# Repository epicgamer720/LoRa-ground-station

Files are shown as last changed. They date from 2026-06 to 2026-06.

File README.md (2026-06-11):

# LoRa Ground Station

A compact, USB-connected LoRa receiver for pulling live telemetry off my rockets in flight. Built around an RP2040 + Semtech SX1262 on the 902–928 MHz ISM band, designed from scratch in KiCad. Pairs with my [rocket flight controller](https://github.com/epicgamer720/Flight-Controller-for-rockets).






## Why I built it

The flight controller sends telemetry down over LoRa, but that's only half the link — you need something on the ground to actually receive it. Rather than buy an off the shelf LoRa dev board, I wanted to try my hand at RF design. It plugs into a laptop over USB-C and streams the rocket's altitude and position to a terminal or display in real time. It was also my way into RF design getting the 50 Ω antenna trace, the impedance matching, the RF switch, and the SX1262's TCXO reference right is a different challenge from a normal digital board, and I wanted to learn it on real hardware.

## Use cases

- **Live flight telemetry** — receive altitude, velocity, and GPS position from the rocket during flight, in real time.
- **Recovery tracking** — read out the last known GPS coordinates to find the rocket after landing.
- **Range testing** — bench-test link distance and signal quality before committing to a flight.
- **General LoRa receiver / dev tool** — works as a USB LoRa node for any other long-range telemetry or sensor project, not just rockets.

## Specifications

| Subsystem | Part / detail |
|---|---|
| MCU | RP2040 — dual-core Cortex-M0+ |
| Radio | SX1262 — sub-GHz LoRa transceiver |
| Band | 902–928 MHz ISM (915 MHz, US) |
| RF switch | PE4259 — TX/RX antenna switching |
| Reference | 32 MHz TCXO (ECS-TXO) for the radio |
| Antenna | SMA connector |
| Flash | W25Q128 — 16 MB QSPI for firmware |
| Clock | 12 MHz crystal for the RP2040 |
| Power | AP2112K-3.3 LDO, USB-C |
| Controls | 2× tactile buttons (BOOT / RESET) |

## 
## Built with

[KiCad](https://www.kicad.org/) · [Macondo](https://macondo.hackclub.com/)

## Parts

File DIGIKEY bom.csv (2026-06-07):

Index | Quantity | Part Number | Manufacturer Part Number | Description | Customer Reference | Available | Backorder | Unit Price | Extended Price USD
1 | 2 | 2073-RFPC-SMA28-F-ND | RFPC-SMA28-F | SMA VERTICAL PCB JACK |  | 2 | 0 | 1.75000 | 3.50
2 | 3 | 296-50584-1-ND | TPD1E0B04DPLR | TVS DIODE 3.6VWM 10.1VC 2X2SON |  | 3 | 0 | 0.60000 | 1.80
3 | 2 | 2073-USB4105-GF-ACT-ND | USB4105-GF-A | CONN RCP USB2.0 TYP C 16P SMD RA |  | 2 | 0 | 0.80000 | 1.60
4 | 2 | 712-0900FM15K0039001ECT-ND | 0900FM15K0039001E | CER FILTER 895MHZ BAND PASS |  | 2 | 0 | 0.49000 | 0.98
5 | 2 | 535-10261-1-ND | ABM8G-12.000MHZ-18-D2Y-T | CRYSTAL 12.0000MHZ 18PF SMD |  | 2 | 0 | 0.43000 | 0.86

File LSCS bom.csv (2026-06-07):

Index | LCSC# | MPN | Manufacturer | Package | Customer # | Description | RoHS | Quantity | MOQ | Multiple | Unit Price($) | Extended Price($) | Product Link
1 | C272875 | CC0402KRX7R9BB473 | YAGEO | 0402 | C10, C11 | 47nF ±10% 50V Ceramic Capacitor X7R 0402 | yes | 100 | 100 | 100 | 0.0044 | 0.44 | https://www.lcsc.com/product-detail/C272875.html
2 | C97521 | W25Q128JVSIQ | Winbond | SOIC-8-208mil | U5 | 2.7V~3.6V 128Mbit 133MHz SPI SOIC-8-208mil Memory (ICs) RoHS | yes | 2 | 1 | 1 | 2.6399 | 5.28 | https://www.lcsc.com/product-detail/C97521.html
3 | C51118 | AP2112K-3.3TRG1 | DIODES | SOT-25-5 | U4 | 3.3V Positive Fixed SOT-25-5 Voltage Regulators - Linear, Low Drop Out (LDO) Regulators RoHS | yes | 5 | 5 | 5 | 0.1634 | 0.82 | https://www.lcsc.com/product-detail/C51118.html
4 | C470892 | PE4259-63 | pSemi | SC-70-6 | U3 | 10MHz~3GHz SC-70-6 RF Switches RoHS | yes | 2 | 1 | 1 | 0.6297 | 1.26 | https://www.lcsc.com/product-detail/C470892.html
5 | C191341 | SX1262IMLTRT | SEMTECH | QFN-24-EP(4x4) | U2 | 300Kbps -148dBm 150MHz~960MHz 1.8V~3.7V QFN-24-EP(4x4) RF Transceiver ICs RoHS | yes | 2 | 1 | 1 | 3.2486 | 6.50 | https://www.lcsc.com/product-detail/C191341.html
6 | C105872 | RC0402FR-075K1L | YAGEO | 0402 | R7, R8 | 5.1kΩ 62.5mW 50V Thick Film Resistor ±100ppm/℃ ±1% 0402 Chip Resistor - Surface Mount RoHS | yes | 100 | 100 | 100 | 0.0010 | 0.10 | https://www.lcsc.com/product-detail/C105872.html
7 | C106235 | RC0402FR-071KL | YAGEO | 0402 | R2, R6 | 1kΩ 62.5mW 50V Thick Film Resistor ±100ppm/℃ ±1% 0402 Chip Resistor - Surface Mount RoHS | yes | 100 | 100 | 100 | 0.0010 | 0.10 | https://www.lcsc.com/product-detail/C106235.html
8 | C395068 | VHF100505HQ47NJT | FH | 0402 | L3 | 700mA 47nH ±5% 160mΩ 0402 Fixed Inductors RoHS | yes | 100 | 100 | 100 | 0.0055 | 0.55 | https://www.lcsc.com/product-detail/C395068.html
9 | C98055 | LQW15AN15NG00D | muRata | 0402 | L1 | 460mA 15nH ±2% 160mΩ Unshielded Inductor 0402 Fixed Inductors RoHS | yes | 20 | 20 | 20 | 0.0665 | 1.33 | https://www.lcsc.com/product-detail/C98055.html
10 | C85815 | BLM15AX102SN1D | muRata | 0402 | FB1 | 1kΩ@100MHz 1 Line Ferrite Bead 0402 350mA 490mΩ | yes | 100 | 100 | 100 | 0.0113 | 1.13 | https://www.lcsc.com/product-detail/C85815.html
11 | C327068 | CC0402FRNPO9BN390 | YAGEO | 0402 | C7 | 39pF ±1% 50V Ceramic Capacitor NP0 0402 | yes | 100 | 100 | 100 | 0.0045 | 0.45 | https://www.lcsc.com/product-detail/C327068.html
12 | C76947 | GRM1555C1H102JA01D | muRata | 0402 | C6 | 1nF ±5% 50V Ceramic Capacitor C0G 0402 | yes | 100 | 100 | 100 | 0.0073 | 0.73 | https://www.lcsc.com/product-detail/C76947.html
13 | C77177 | GRM1555C1H101JA01D | muRata | 0402 | C5 | 100pF ±5% 50V Ceramic Capacitor C0G 0402 | yes | 100 | 100 | 100 | 0.0050 | 0.50 | https://www.lcsc.com/product-detail/C77177.html
14 | C92361 | CL05A474KA5NNNC | Samsung Electro-Mechanics | 0402 | C3 | 470nF ±10% 25V Ceramic Capacitor X5R 0402 | yes | 20 | 10 | 10 | 0.0162 | 0.32 | https://www.lcsc.com/product-detail/C92361.html
15 | C76906 | GJM1555C1H3R3BB01D | muRata | 0402 | C25, C26, C8, C9 | 3.3pF 50V Ceramic Capacitor C0G 0402 | yes | 50 | 50 | 50 | 0.0317 | 1.59 | https://www.lcsc.com/product-detail/C76906.html
16 | C29266 | CL05A105KO5NNNC | Samsung Electro-Mechanics | 0402 | C21, C24 | 1uF ±10% 16V Ceramic Capacitor X5R 0402 | yes | 100 | 100 | 100 | 0.0038 | 0.38 | https://www.lcsc.com/product-detail/C29266.html
17 | C107002 | CC0402JRNPO9BN270 | YAGEO | 0402 | C12, C13 | 27pF ±5% 50V Ceramic Capacitor NP0 0402 | yes | 100 | 100 | 100 | 0.0019 | 0.19 | https://www.lcsc.com/product-detail/C107002.html
18 | C60474 | CC0402KRX7R7BB104 | YAGEO | 0402 | C1, C14, C15, C16, C17, C18, C19, C2, C20, C22, C23, C27, C4 | 100nF ±10% 16V Ceramic Capacitor X7R 0402 | yes | 100 | 100 | 100 | 0.0018 | 0.18 | https://www.lcsc.com/product-detail/C60474.html
19 | C2040 | RP2040 | Raspberry Pi | LQFN-56(7x7) |  | 133MHz 30 LQFN-56(7x7) Microcontrollers RoHS | yes | 2 | 1 | 1 | 0.9482 | 1.90 | https://www.lcsc.com/product-detail/C2040.html
20 | C284479 | ARG02FTC27R4 | Viking | 0402 |  | 27.4Ω ±1% 62.5mW 0402 Thin Film Resistor | yes | 200 | 100 | 100 | 0.0059 | 1.18 | https://www.lcsc.com/product-detail/C284479.html

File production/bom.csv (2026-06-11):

Designator | Footprint | Quantity | Value | LCSC Part #
C1, C14, C15, C16, C17, C18, C19, C2, C20, C22, C23, C27, C4 | 0402 | 13 | 100 nF
C10, C11 | 0402 | 2 | 47 nF
C12, C13 | 0402 | 2 | 27 pF
C21, C24 | 0402 | 2 | 1 uF
C25, C26 | 0603 | 2 | 10 uF
C3 | 0402 | 1 | 470 nF
C5 | 0402 | 1 | 100 pF
C6 | 0402 | 1 | 1 nF
C7 | 0402 | 1 | 39 pF
C8, C9 | 0402 | 2 | 3.3 pF
FB1 | BEADC1005X55N | 1 | BLM15AX102SN1D
FL1 | Balun_Johanson_0900FM15K0039 | 1 | 0900FM15K0039
J1 | GRADCONN_RFPC-SMA28-F | 1 | RFPC-SMA28-F
J2 | USB_C_Receptacle_GCT_USB4105-xx-A_16P_TopMnt_Horizontal | 1 | USB_C_Receptacle_USB2.0_14P
L1 | 0402 | 1 | 15 nH
L2 | 0402 | 1 | 15 uH
L3 | 0402 | 1 | 47 nH
R1 | 0402 | 1 | 100
R2, R6 | 0402 | 2 | 1K
R3, R4 | 0402 | 2 | 27.3
R5, R9 | 0402 | 2 | 10k
R7, R8 | 0402 | 2 | 5.1k
SW1 | PTS636SMG25JSMTRLFS | 1 | BOOT
SW2 | PTS636SMG25JSMTRLFS | 1 | RESET
U1 | QFN-56-1EP_7x7mm_P0.4mm_EP3.2x3.2mm | 1 | RP2040
U2 | QFN-24-1EP_4x4mm_P0.5mm_EP2.6x2.6mm | 1 | SX1262IMLTRT
U3 | SOT-363_SC-70-6 | 1 | PE4259
U4 | SOT-23-5 | 1 | AP2112K-3.3
U5 | SOIC-8_5.3x5.3mm_P1.27mm | 1 | W25Q128JVS
U6 | DPL0002A-MFG | 1 | TPD1E0B04DPLR
Y1 | OSC_ECS-TXO-25CSMV-320-DY-TR | 1 | ECS-TXO-25CSMV-320-DY-TR
Y2 | XTAL_ABM8G-12.000MHZ-18-D2Y-T | 1 | ABM8G-12.000MHZ-18-D2Y-T

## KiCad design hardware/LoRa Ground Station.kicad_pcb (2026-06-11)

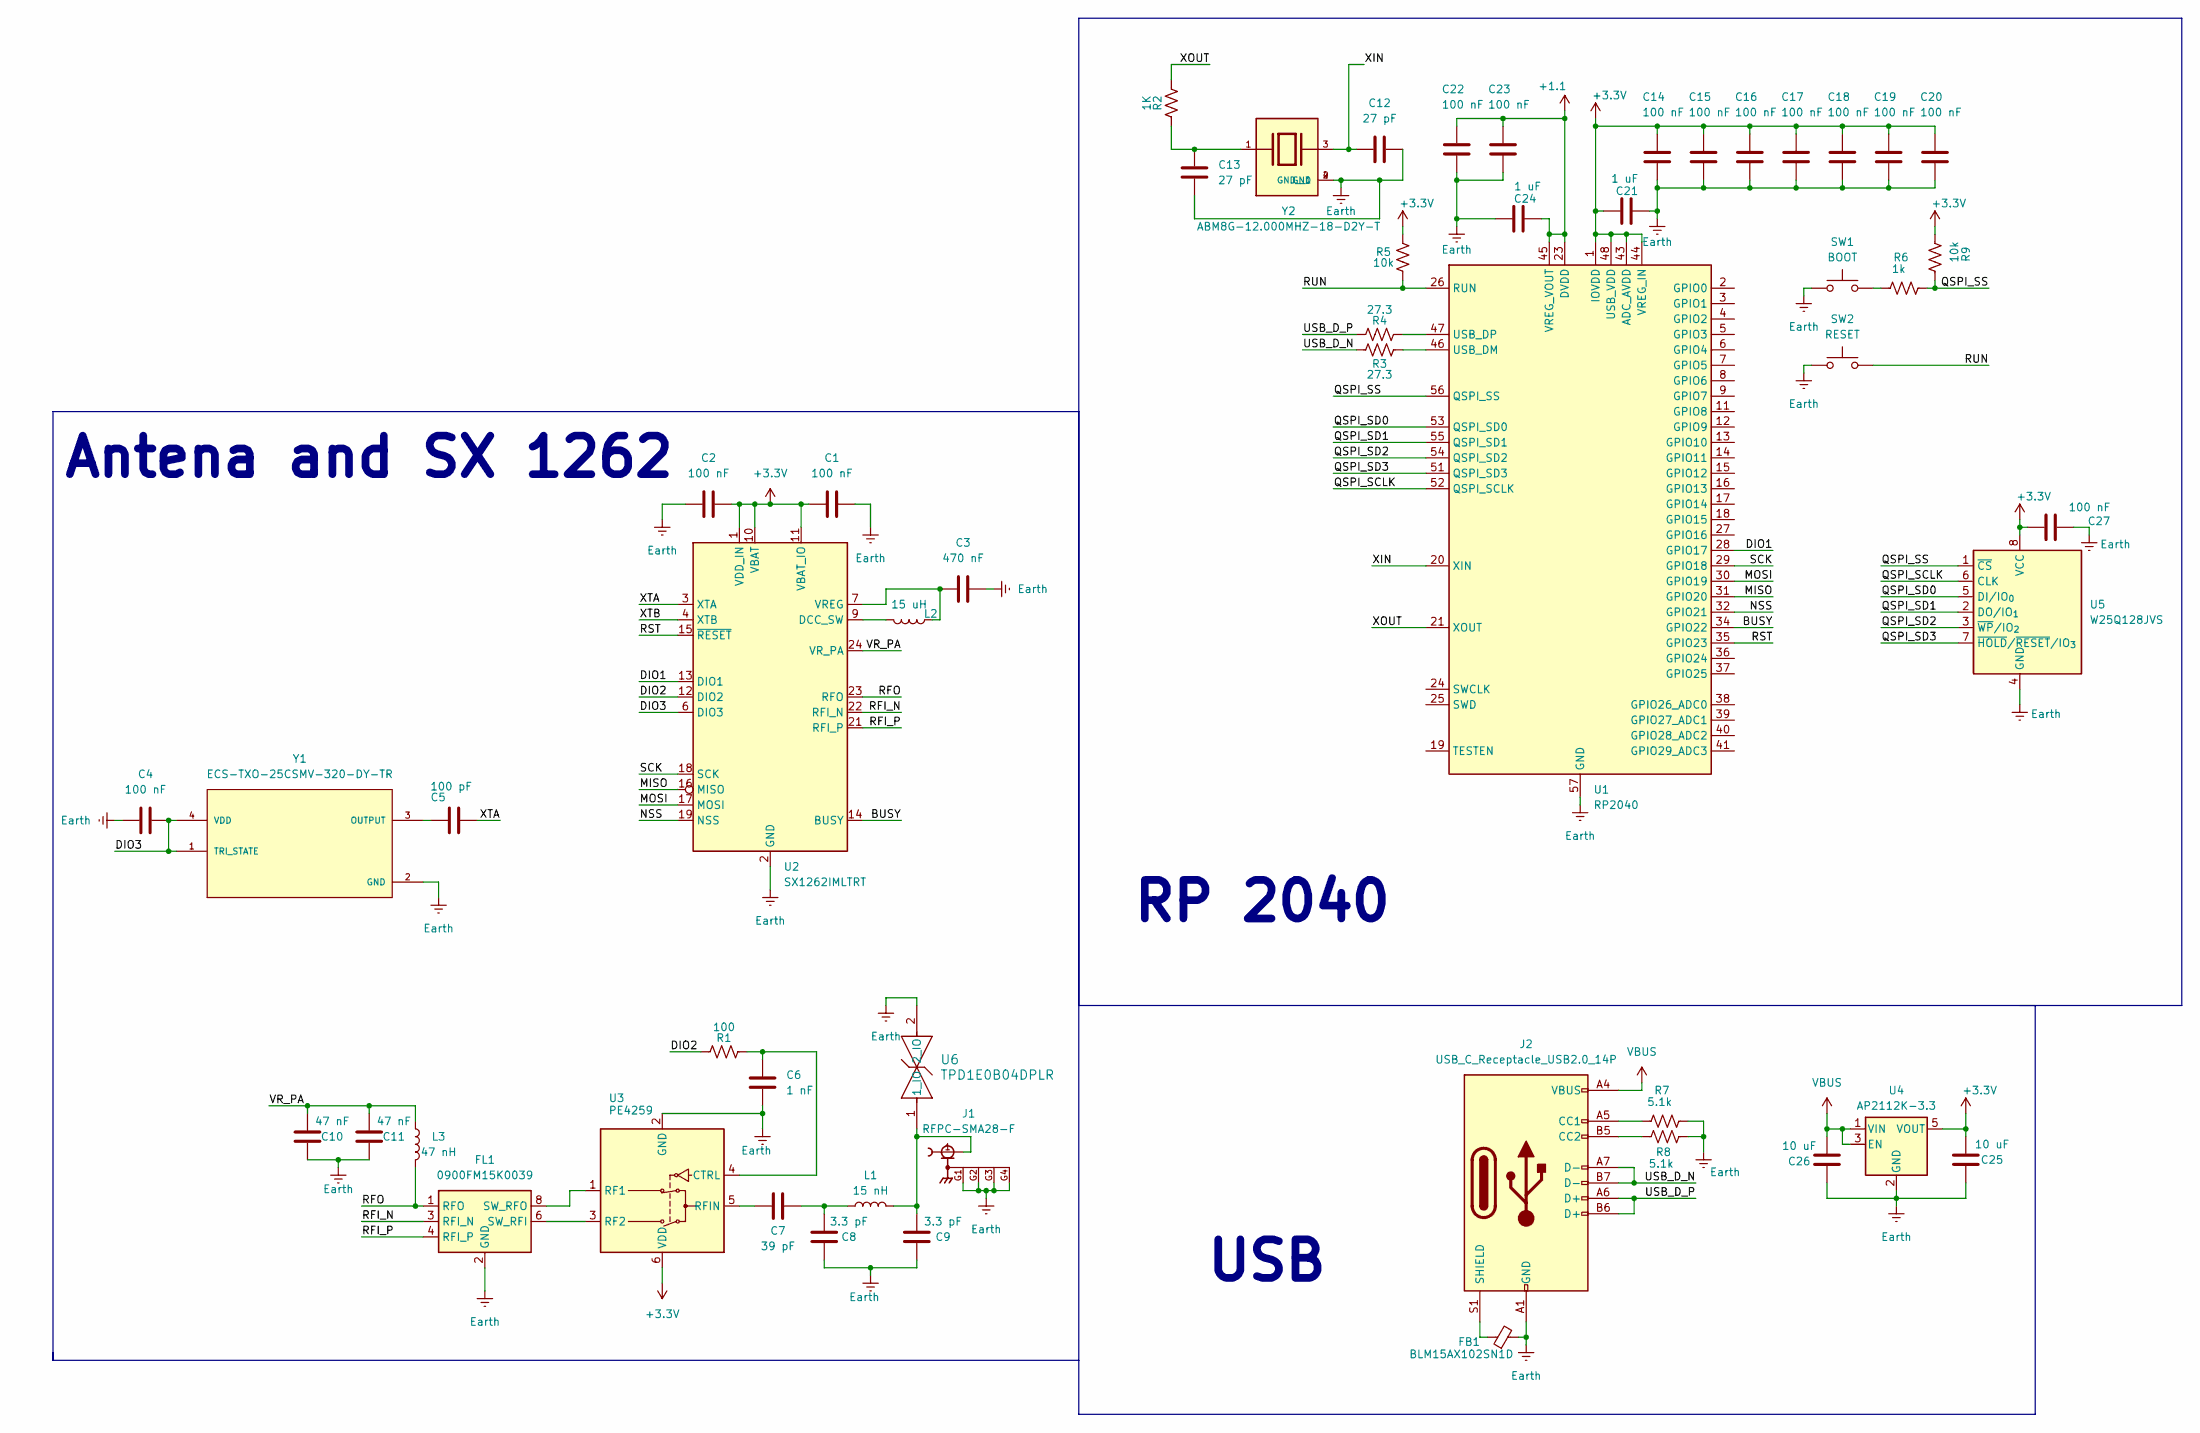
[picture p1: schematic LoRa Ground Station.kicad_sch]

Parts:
C1, C2, C4, C14, C15, C16, C17, C18, C19, C20, C22, C23, C27: 100 nF; C_0402_1005Metric
C3: 470 nF; C_0402_1005Metric
C5: 100 pF; C_0402_1005Metric
C6: 1 nF; C_0402_1005Metric
C7: 39 pF; C_0402_1005Metric
C8, C9: 3.3 pF; C_0402_1005Metric
C10, C11: 47 nF; C_0402_1005Metric
C12, C13: 27 pF; C_0402_1005Metric
C21, C24: 1 uF; C_0402_1005Metric
C25, C26: 10 uF; C_0603_1608Metric
FB1: BLM15AX102SN1D; BEADC1005X55N
FL1: 0900FM15K0039; Balun_Johanson_0900FM15K0039
J1: RFPC-SMA28-F; GRADCONN_RFPC-SMA28-F; PARTREV 1.0
J2: USB_C_Receptacle_USB2.0_14P; USB_C_Receptacle_GCT_USB4105-xx-A_16P_TopMnt_Horizontal
L1: 15 nH; L_0402_1005Metric
L2: 15 uH; L_0402_1005Metric
L3: 47 nH; L_0402_1005Metric
R1: 100; R_0402_1005Metric
R2: 1K; R_0402_1005Metric
R3, R4: 27.3; R_0402_1005Metric
R5, R9: 10k; R_0402_1005Metric
R6: 1k; R_0402_1005Metric
R7, R8: 5.1k; R_0402_1005Metric
SW1: BOOT; PTS636SMG25JSMTRLFS
SW2: RESET; PTS636SMG25JSMTRLFS
U1: RP2040; QFN-56-1EP_7x7mm_P0.4mm_EP3.2x3.2mm
U2: SX1262IMLTRT; QFN-24-1EP_4x4mm_P0.5mm_EP2.6x2.6mm
U3: PE4259; SOT-363_SC-70-6
U4: AP2112K-3.3; SOT-23-5
U5: W25Q128JVS; SOIC-8_5.3x5.3mm_P1.27mm
U6: TPD1E0B04DPLR; DPL0002A-MFG
Y1: ECS-TXO-25CSMV-320-DY-TR; OSC_ECS-TXO-25CSMV-320-DY-TR
Y2: ABM8G-12.000MHZ-18-D2Y-T; XTAL_ABM8G-12.000MHZ-18-D2Y-T; PARTREV 08.13.15

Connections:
+1.1: C22.1, C23.1, C24.2, U1.23 (DVDD), U1.45 (VREG_VOUT), U1.50 (DVDD)
+3.3V: C1.1, C2.2, C14.1, C15.1, C16.1, C17.1, C18.1, C19.1, C20.1, C21.1, C25.2, C27.2, R5.2, R9.1, U1.1 (IOVDD), U1.10 (IOVDD), U1.22 (IOVDD), U1.33 (IOVDD), U1.42 (IOVDD), U1.43 (ADC_AVDD), U1.44 (VREG_IN), U1.48 (USB_VDD), U1.49 (IOVDD), U2.1 (VDD_IN), U2.10 (VBAT), U2.11 (VBAT_IO), U3.6 (VDD), U4.5 (VOUT), U5.8 (VCC)
/BUSY: U1.34 (GPIO22), U2.14 (BUSY)
/DIO1: U1.28 (GPIO17), U2.13 (DIO1)
/DIO2: R1.1, U2.12 (DIO2)
/DIO3: C4.2, U2.6 (DIO3), Y1.1 (TRI_STATE), Y1.4 (VDD)
/MISO: U1.31 (GPIO20), U2.16 (MISO)
/MOSI: U1.30 (GPIO19), U2.17 (MOSI)
/NSS: U1.32 (GPIO21), U2.19 (NSS)
/QSPI_SCLK: U1.52 (QSPI_SCLK), U5.6 (CLK)
/QSPI_SD0: U1.53 (QSPI_SD0), U5.5 (DI/IO_{0})
/QSPI_SD1: U1.55 (QSPI_SD1), U5.2 (DO/IO_{1})
/QSPI_SD2: U1.54 (QSPI_SD2), U5.3 (~WP/IO_{2})
/QSPI_SD3: U1.51 (QSPI_SD3), U5.7 (~HOLD/~RESET/IO_{3})
/QSPI_SS: R6.2, R9.2, U1.56 (QSPI_SS), U5.1 (~CS)
/RFI_N: FL1.3 (RFI_N), U2.22 (RFI_N)
/RFI_P: FL1.4 (RFI_P), U2.21 (RFI_P)
/RFO: FL1.1 (RFO), L3.2, U2.23 (RFO)
/RST: U1.35 (GPIO23), U2.15 (~RESET)
/RUN: R5.1, SW2.2, U1.26 (RUN)
/SCK: U1.29 (GPIO18), U2.18 (SCK)
/USB_D_N: J2.A7 (D-), J2.B7 (D-), R3.2
/USB_D_P: J2.A6 (D+), J2.B6 (D+), R4.1
/VR_PA: C10.2, C11.2, L3.1, U2.24 (VR_PA)
/XIN: C12.2, U1.20 (XIN), Y2.3
/XOUT: R2.2, U1.21 (XOUT)
/XTA: C5.1, U2.3 (XTA)
/XTB: U2.4 (XTB)
Earth: C1.2, C2.1, C3.2, C4.1, C6.1, C8.1, C9.1, C10.1, C11.1, C12.1, C13.2, C14.2, C15.2, C16.2, C17.2, C18.2, C19.2, C20.2, C21.2, C22.2, C23.2, C24.1, C25.1, C26.1, C27.1, FB1.2, FL1.2 (GND), FL1.5 (GND), FL1.7 (GND), FL1.9 (GND), FL1.10 (GND), J1.G1, J1.G2, J1.G3, J1.G4, J2.A1 (GND), J2.A12 (GND), J2.B1 (GND), J2.B12 (GND), R7.2, R8.2, SW1.1, SW2.1, U1.57 (GND), U2.2 (GND), U2.5 (GND), U2.8 (GND), U2.20 (GND), U2.25 (GND), U3.2 (GND), U4.2 (GND), U5.4 (GND), U6.2 (2_IO), Y1.2 (GND), Y2.2 (GND), Y2.4 (GND__1)
unnamed: C7.2, C8.2, L1.1
unnamed: C13.1, R2.1, Y2.1
unnamed: FL1.6 (SW_RFI), U3.3 (RF2)
unnamed: FL1.8 (SW_RFO), U3.1 (RF1)
unnamed: J2.A5 (CC1), R7.1
unnamed: J2.B5 (CC2), R8.1
unnamed: FB1.1, J2.S1 (SHIELD)
unnamed: R6.1, SW1.2
unnamed: R3.1, U1.46 (USB_DM)
unnamed: R4.2, U1.47 (USB_DP)
unnamed: L2.2, U2.9 (DCC_SW)
unnamed: C3.1, L2.1, U2.7 (VREG)
unnamed: C6.2, R1.2, U3.4 (CTRL)
unnamed: C7.1, U3.5 (RFIN)
unnamed: C9.2, J1.1, L1.2, U6.1 (1_IO)
unnamed: C5.2, Y1.3 (OUTPUT)
VBUS: C26.2, J2.A4 (VBUS), J2.A9 (VBUS), J2.B4 (VBUS), J2.B9 (VBUS), U4.1 (VIN), U4.3 (EN)

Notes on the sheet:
Antena and SX 1262
RP 2040
USB

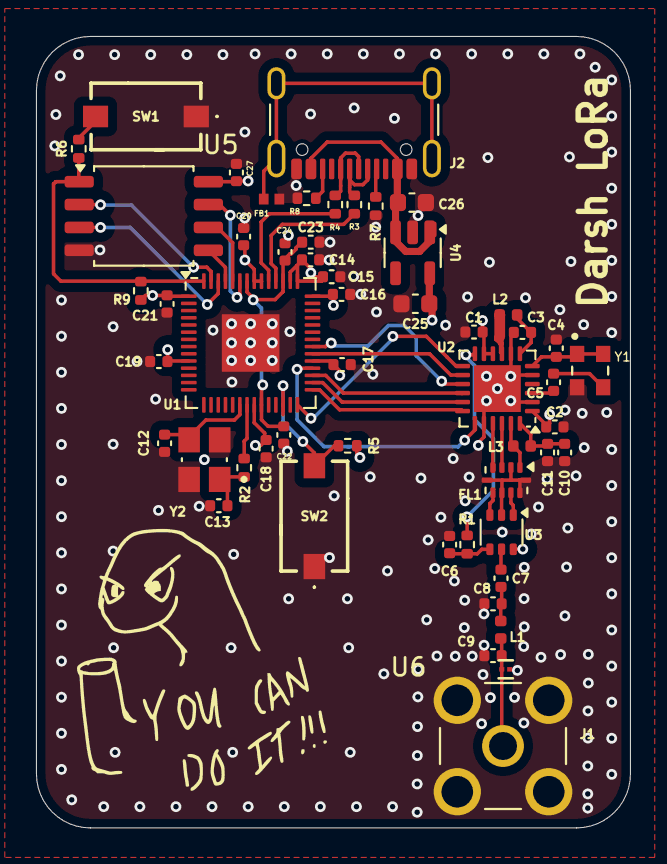
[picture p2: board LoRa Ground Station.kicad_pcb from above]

Board: 4 copper layers, 33.0 x 44.0 mm, 53 parts (0 on the bottom side), 45 nets.

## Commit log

2026-05-30 Create Kicad
2026-06-11 Update antenna description in README.md
